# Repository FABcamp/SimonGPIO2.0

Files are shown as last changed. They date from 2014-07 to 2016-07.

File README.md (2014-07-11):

SimonGPIO2.0
============

SimonGPIO files for UCI fabcamp 2.0

includes:
 - Eagle BRD files, requires the [Sparkfun Eagle library][] and [Adafruit Eagle library][]
[Sparkfun Eagle library]: <https://github.com/sparkfun/SparkFun-Eagle-Libraries>
[Adafruit Eagle library]: <https://github.com/adafruit/Adafruit-Eagle-Library>
 - Fritzing PCB layout with custom part files for [Square buttons sold by Adafruit][]
[Square buttons sold by Adafruit]: <http://www.adafruit.com/products/1010>
 - solidworks and STL files for the Case and a test model of the finished PCB
 - scratch files and [instructions][] for running the project
[instructions]: https://github.com/FabCamp/SimonGPIO2.0/blob/master/Documentation/Scratch%20Instructions.md
 - [Bill of Materials][] for the project
[Bill of Materials]: https://github.com/FabCamp/SimonGPIO2.0/blob/master/Documentation/Bill%20Of%20Materials.md
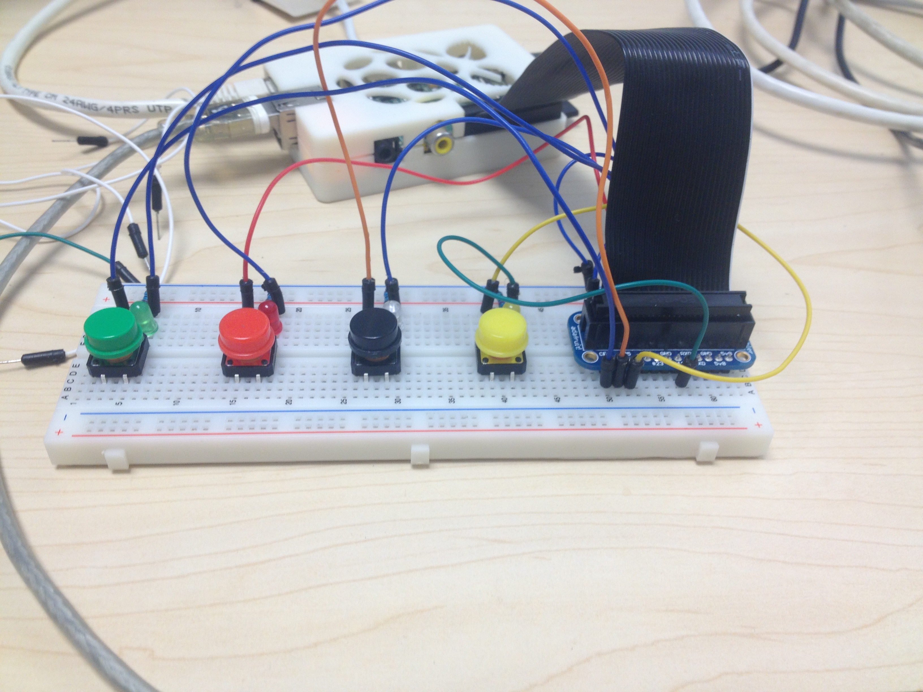
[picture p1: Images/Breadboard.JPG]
breadboard

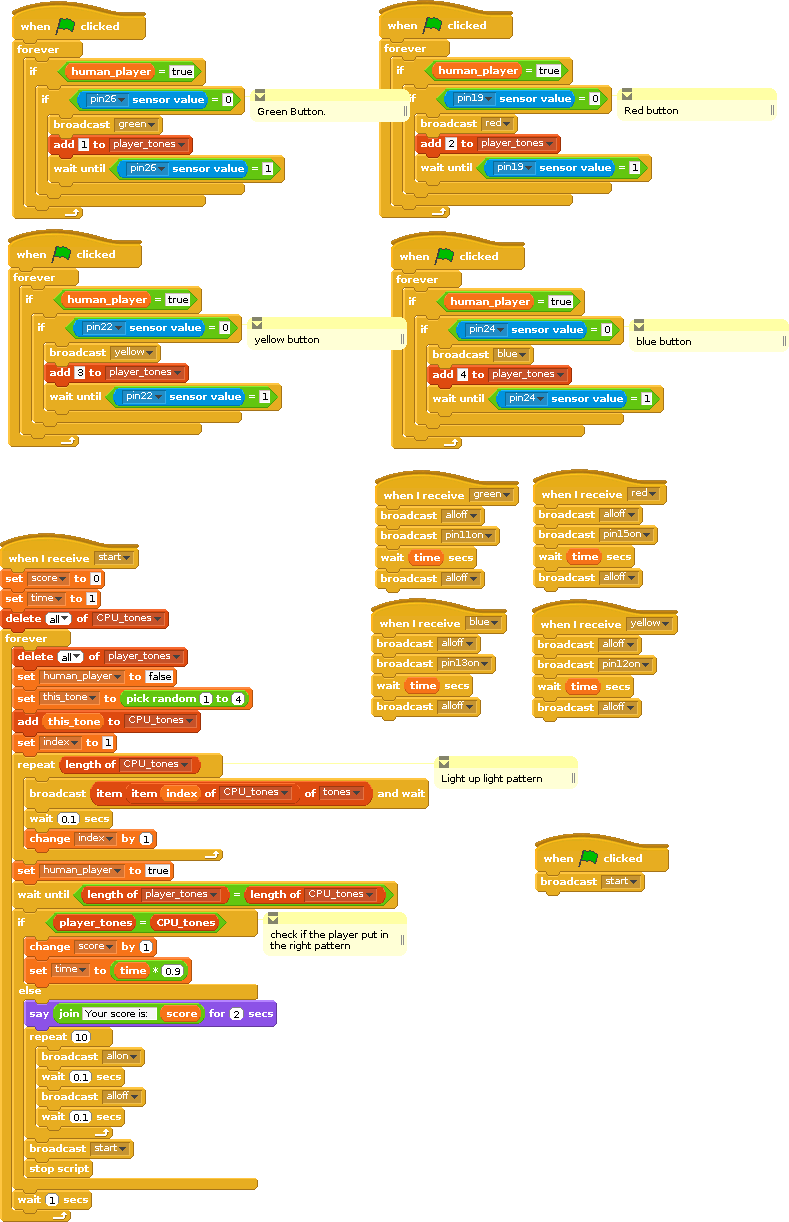
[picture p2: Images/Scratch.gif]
Scratch Code


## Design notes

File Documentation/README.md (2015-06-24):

Documentation
=============

######These documents will tell you everything you need to know about building the SimonGPIO project

- [Bill Of Materials][1]

[1]: https://github.com/FABcamp/SimonGPIO2.0/blob/master/Documentation/Bill%20Of%20Materials.md

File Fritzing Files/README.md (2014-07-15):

Fritzing Files
==============
Contents of this Directory:

1. [Fritzing Custom Parts.fzbz](https://github.com/FabCamp/SimonGPIO2.0/blob/master/Fritzing%20Files/Fritzing%20Custom%20Parts.fzbz): Custom parts for this project. All `.fzz` files here will work without this file, but they may be useful for future projects involving [square colorful buttons sold by Adafruit](http://www.adafruit.com/products/1010).
2. [Fritzing Diagram Full](https://github.com/FabCamp/SimonGPIO2.0/blob/master/Fritzing%20Files/Fritzing%20Diagram%20Full.fzz): The full diagram for the breadboard used in this project. Includes all parts necessary, which are the colorful square buttons (above) and [Adafruit Pi Cobbler]().

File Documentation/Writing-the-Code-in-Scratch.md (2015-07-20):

Writing The Code
================
######This page will guide you through writing the code for your simon game in the Scratch programming environment

_Teachers: Before giving these instructions, make sure you have [covered all the skills necessary!](https://github.com/FABcamp/SimonGPIO2.0/blob/master/Documentation/Topics-to-Cover-Teaching-Scratch.md)_

finished code

Setting Up
----------

When you start up the raspberry pi, you will see a desktop. The raspberry pi uses an operating system called Linux, which is similar to your Windows or Mac computers at home. To open ScratchGPIO, doubleclick on its icon on the desktop. If you open the normal Scratch, you will not be able to interface with your circuit. 

Once you have opened ScratchGPIO, go to file>new to clear the canvas and start a new project.

Beginning the Script
--------------------

First, we must have our script start when we begin the program. From the “control” tab on the upper left, drag into the canvas the first block, which should say “when (flag) clicked”. this will mean the block of code are creating will run as soon as we hit either the little green flag on the upper right, or hit the “enter” key on the keyboard. 

Now we need to set up our variables. in the variables tab, click `add variable` to create a variable called `score`, and another called `time`. In the lower half of this tab, click `add list` and create 2 lists called `CPU_tones` and  `player_tones` in the same way. Bring in 2 `set variable` blocks. change one to the `score` variable, and the other to the `time` variable. Set `score` to `0` and `time` to `1`. We must also reset our list of computer-created tones, so bring down the `delete () of []` block, setting it to **delete all of `CPU_tones`**. Now add a “forever” loop from the control tab. This will run *indefinitely* until we stop our script. Add another `delete` block to **delete all of `Player_tones`** inside the forever loop.

In our project, we also have a variable called `human_player`. This keeps track of when the player is in control of the simon game. first, the game must tell the player what the pattern is, so it is not the human player’s turn right now. add a block to **set `human_player` to `false`**. We should also have the game add numbers to this pattern, which will be between 1 and 4. each number will refer to one button or light on the board. under the variables tab, add a block to **add a value to `CPU_tones`**. In the value slot, drag in the block from the Operators tab to **create a random value** and change the second value to 4, not 10. 

Now the cumputer must play back the list of tones it has generated. This will step through each item in our list of `CPU_tones` and play each one out. Scratch doesnt have a function to do this for us, so we need to write it ourselves. Create a new variable called `index` to keep track of which item in our `CPU_tones` list we are playing. Add a block to **set `index` to 1** and add a block from the control tab to **repeat (value)**. For this value, add a block from variables for `Length of [CPU_tones]` Inside this, we will play the tone. Add a block to **broadcast a value**. for this value, bring in a block for `Item (x) of [CPU_tones]` and add the variable `index` for the item number. Now add a block to **wait 0.1 seconds**, and another to **change `index` by 1. How does this work? What we are saying, is first to run this chunk of code the same number of times as there are lights to turn on. on each of these, we are saying to play item x of the list, so if x is 1, we are broadcasting the first item, if x is 2, we are broadcasting the second item. Then we change x by 1 so the next value is used the next time the chunk of code runs. 

Now the human player must play back the pattern on the buttons. add another block to **set `human_player` to `true`**. For the human to be able to play the pattern, we must have the code detect when buttons are pressed, so we must work on another code block to do that. 

Reading the Button Inputs
-------------------------

Drag in another "When (flag) clicked" block from the control tab. under it, **add a forever loop**, and inside it, **add an if block from the control tab**. This will check if a condition is met. add another if block inside it. These blocks have to check:
  1. *if* it is the players turn to push the buttons 
  2. *if* the button is being pushed. 

From the Operators tab, **drag an "equals" block into each of the hexagonal sockets on the 2 if blocks.** in the first one, drag `human_player` into the first half of the `=` and type “true” into the second half. In the second if, drag a "sensor value" block from the sensing tab, and select `pin26`, the pin for our green button, from its drop down menu. Type “0” into the second half. In our circuit, the buttons are connected to ground, or 0, when they are pressed

Inside these 2 Ifs, add a yellow "broadcast block "from the control tab. in its drop down menu, select `new` and type in “1”. this will tell the red light to turn on later in the script. from the variables tab **add a block to add “1” to `player_tones.`** Under it, from the control tab, add a new block to "wait until <>". right click on the green equals on your bottom if, select duplicate, then drag it into the hexagonal socket on your Wait Until block. change the second value to “1”. this waits for the button to be released before allowing it to trigger again.

Duplicate this block 3 times, and change the pin values, broadcast values, and values to add to player_tones to match the 4 buttons on your board using the following table:

Deciding Wins and Losses
------------------------

|color |number|pin name|
|:-----|:----:|:---|
|green |1 |pin26 |
|red |2 |pin19 |
|blue  |3 |pin24 |
|yellow|4 |pin22 |

to let you press the buttons, go back to your first, main block of code and add a block from the control tab to "wait until < >". in it, add an "equals" block, and in each half, add the “length of” block from the variables tab. change them so one is `player_tones` and the other is `CPU_tones`. Order does not matter here. This waits until the player has pressed all the buttons they need to before advanceing in the game

if you start the script now, you should see you should be able to push the buttons, and the `player_tones` list will change as you press them. However, the game doesn't care what buttons you press, so we need to check if the buttons the player pressed (`player_tones`) is the same as the tones the computer created(`CPU_tones`). For this, we need a special kind of *if* called an *if else*. these are also under control. add one, and add another equals block into its hexagon socket. In an if else, the condition given is checked, and then runs the first half of the "E". however, if it is false, it will run the second half of the "E".

In each half of the hexagon socket, add `player_tones` and `CPU_tones`. Order doesn’t matter here. this checks if the list of buttons the player pressed is the same as, or equal to, the list of colors the computer presented them. *If* it is, the player won that round, and our code will lead into the first part of the “E”. *else*, the player lost, it will go to the second half of the “E”, and the game should end. 

If the player won, they should get another point, so add a block from variables to change score by one. We also want the game to go faster, so our time delay `time` should be changed. We can change this to 9/10 of what it was in the last round by adding a few blocks to **set time to (time * 0.9).** The multiplication block is under operators. Feel free to change 0.9 to another number, but if you make it too low (like 0.1), the game will get too fast too quickly. 

Under else, we need to end the game. from the Looks tab, add a block to say “you made a mistake” for 2 seconds. also add a "stop all" block from control. Finally, add a block to wait `1` second from the control tab, to make sure the game doesn't start playing the next pattern until the player is ready. 

Adding Outputs for LEDs
-----------------------

If you play the game now, it may be difficult, because the lights aren't turning on!

we need to add some blocks to turn the lights on! If you look back over our script, we have blocks broadcasting lots of numbers. This is like they are yelling into the air “ONE!” as loud as possible, and another block can listen until they hear that symbol. 

Under control, add a block for "When i receive []". Under this, we will add some more broadcasts to turn the lights on. Another thing our broadcasts can do is control electricity! to do this, we will make more broadcasts, saying things like `allon` or `pin15on` or `pin12off`. these talk to the raspberry pi telling it to change its outputs. Under this, add 2 broadcast blocks, a wait block, and another broadcast block. Duplicate this 3 times and change the broadcasts in the top blocks to numbers 1-4. in the first broadcast, have it say “alloff”, the second say “pin#on” and have the third be “pin#off”. this number should match the broadcast number (which color it is) from this table. You should be done now, enjoy the game!

|number|on message|off message|
|:----:|:---:|:---:|
|1 |pin11on |pin11off |
|2 |pin15on |pin15off |
|3 |pin13on |pin13off |
|4 |pin12on |pin12off |

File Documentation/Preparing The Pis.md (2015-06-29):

Preparing The Raspberry Pis
=================

###### Initial setup

We bought a Cana kit Raspberry Pi Complete Starter Kit for each student. The kit includes the Pi, a case, an SD card, a Wifi adapter, a power supply, and an HDMI cable. Unfortunately, we do not have acess to the university Wifi without registering the MAC addresses of each pi, so all software had to be installed beforehand. In the process of opening each kit to install the cases, we removed the SD card for cloning.

-----------------

###### Cloning the SD cards

We used a [Startech.com USB cloner][1] to clone all the SD cards (though a USB hub and some simple scripting could also work) along with some cheap $1.50 micro SD card reades from Dyso Japan. 

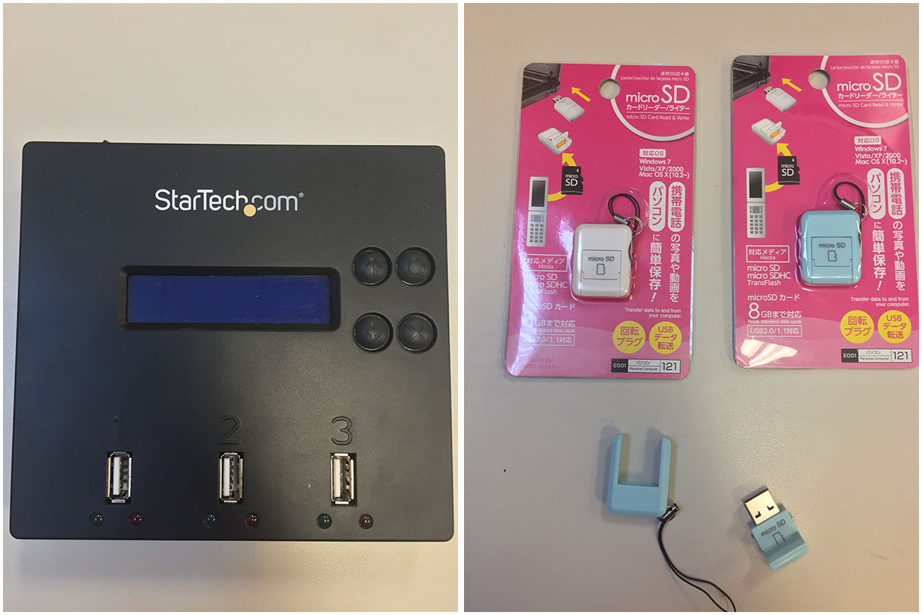
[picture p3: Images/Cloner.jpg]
Cloner


[1]: http://www.startech.com/HDD/Duplicators/USB-1-to-2-Standalone-Flash-Drive-Duplicator-Eraser~USBDUP12
[2]: https://raw.githubusercontent.com/FABcamp/SimonGPIO2.0/master/Images/Cloner.jpg

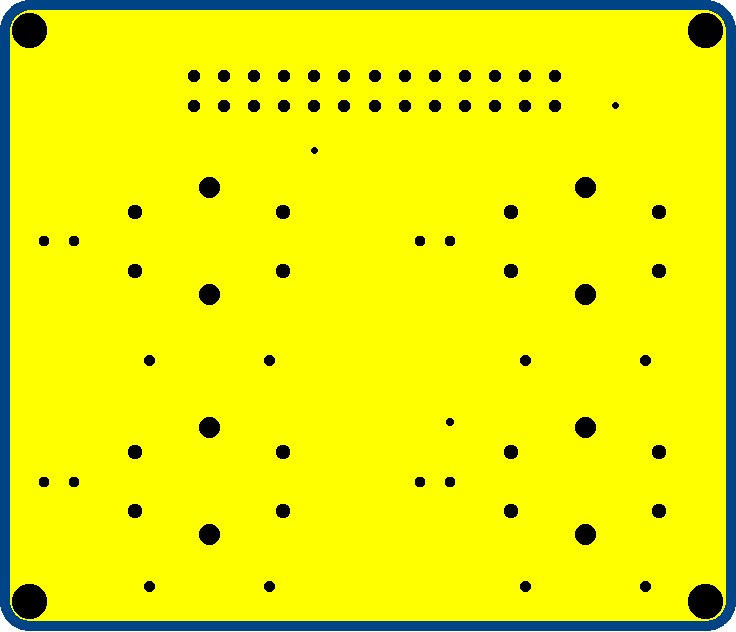
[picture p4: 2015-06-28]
Images/PCB_bottom.png

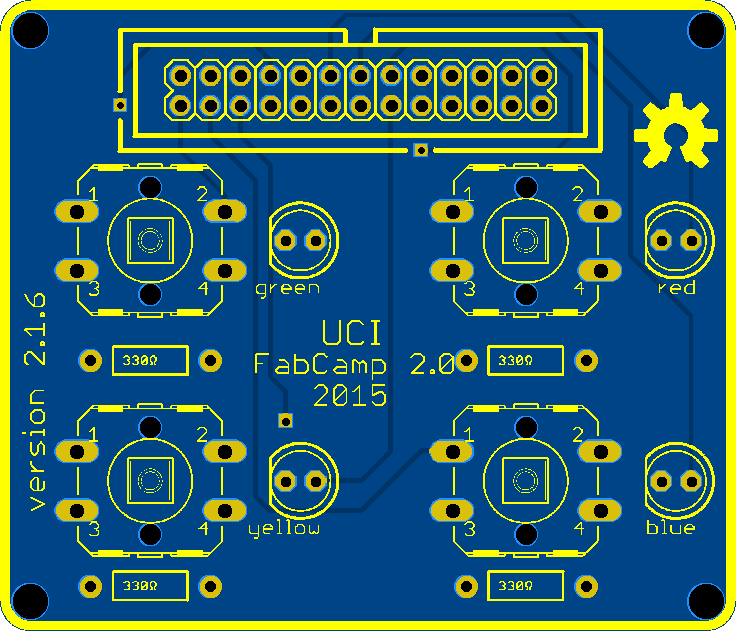
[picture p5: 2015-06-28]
Images/PCB_top.png

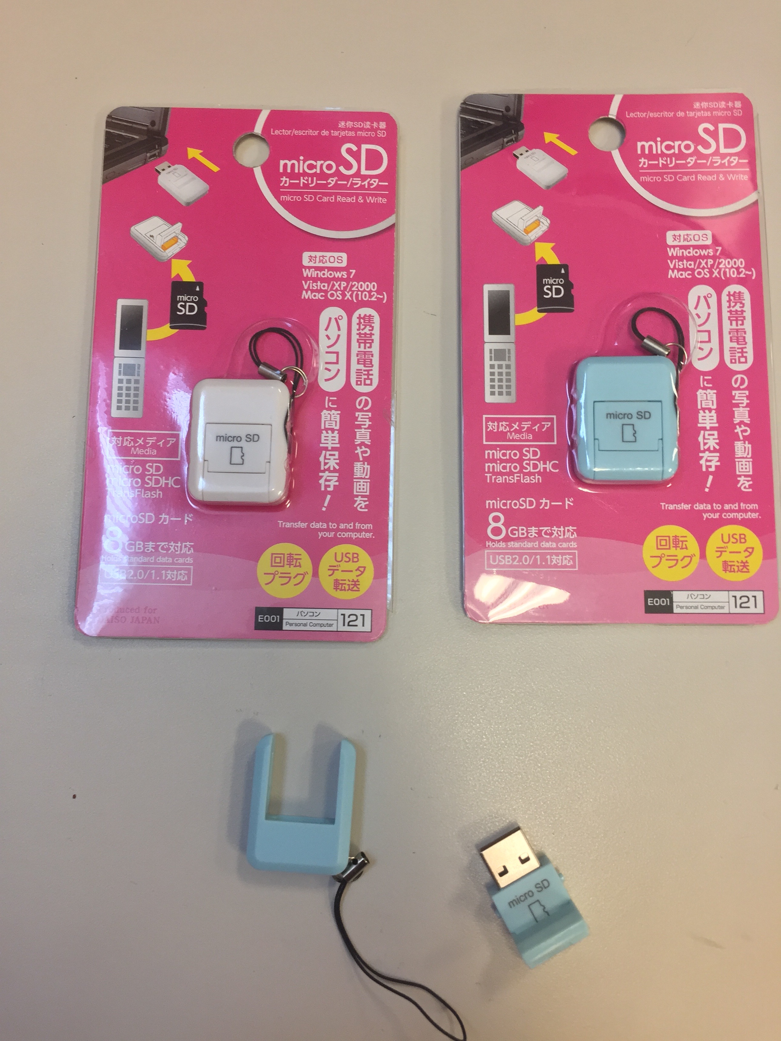
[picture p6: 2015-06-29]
Images/Readers.jpg

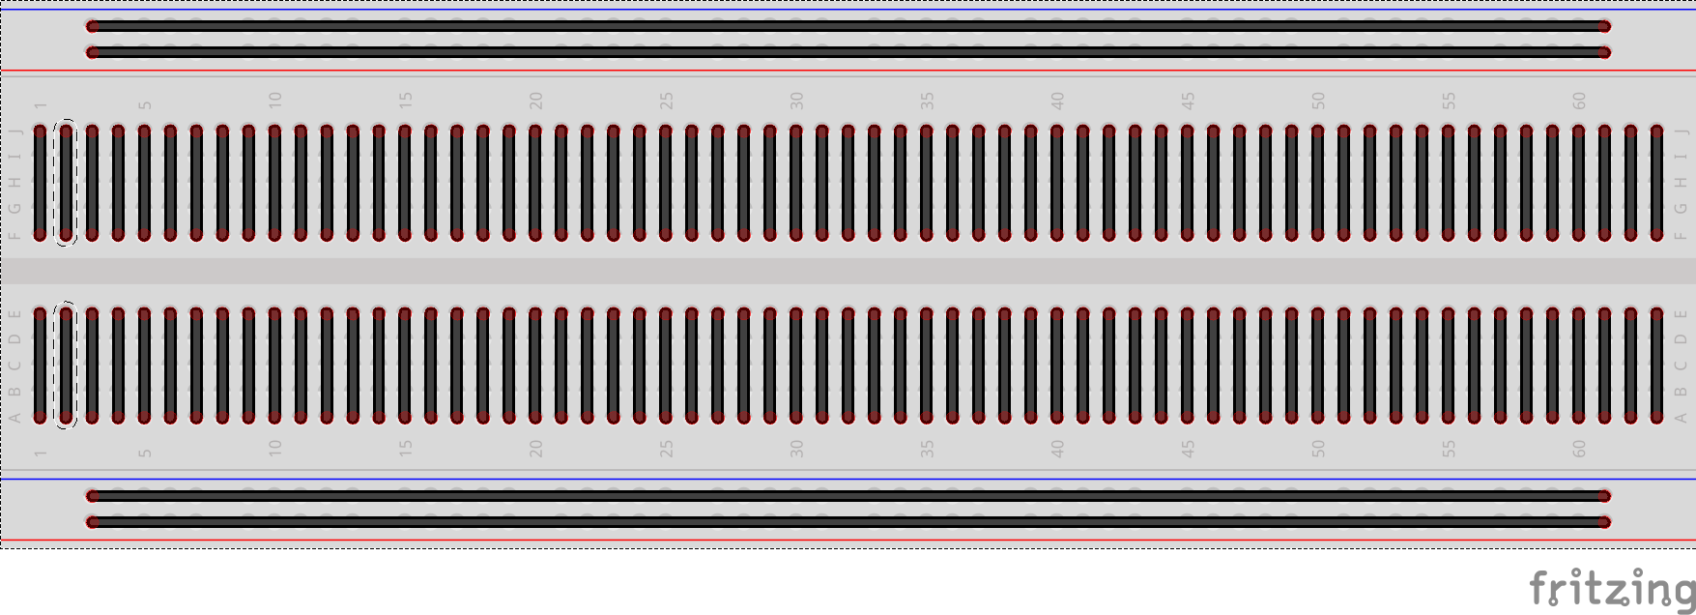
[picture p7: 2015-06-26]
Images/Breadboard Connections.png

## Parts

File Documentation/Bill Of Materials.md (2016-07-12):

Bill Of Materials
=================

###### All the materials necessary to build the SimonGPIO2.0 Project

--------------------------------------------------------------------

#### For Each Student

| Item | Source | Product SKU  | Unit Price | Quantity  | Subtotal |
| --- | --- |:---:| --- |:---:| --- |
| Raspberry Pi 3 | [Newark][1] | #77Y6520  | $35.00 | 1 | $35.00 |
| Raspberry pi Case | [Newark][17] | #77Y6512  | $6.99 | 1 | $6.99 |
| Micro SD card | [Amazon][14] |  B01BMJ25ZA  | $7.49 | 1 | $7.49 |
| Power Supply | [Amazon][15] |  B00MARDJZ4  | $10.00 | 1 | $10.00 |
| HDMI Cable | [Monoprice][16]| #3871 | $2.00 | 1 | $2.00 |
| Downgrade Cable | [Adafruit][2]  | #1986 | $2.95 | 1 | $2.95 |
| HDMI-DVI adapter | [Monoprice][3] | #2029 | $2.28 | 1 | $2.28 |
| Breadboard with Jumpers| [Amazon][4] |  B008A9UP1C  | $11.69 | 1 | $11.69 |
| Pi-Cobbler W/ Cable | [Adafruit][5]  | #1754 | $6.25 | 1 | $6.25 |
| Colored Square buttons | [Adafruit][7]  | #1010 | $5.95 | 1/3 | $1.98 |
| Assorted LEDs (RGBY) | [Sparkfun][8]  | Com-12062  | $2.95 | 1/5 | $0.59 |
| 330Ω resistors x20 | [Digikey][9] | 330ETR-ND  | $0.01 | 1/5 | $0.01 |
| 26 pin shrouded header | [Digikey][11]  |  ED10526-ND  | $0.40 | 1 | $0.40 |
| Plastic Spacer | [McMaster][12] |  #92825A005  | $6.18 | 1/5 | $1.24 |
| 316 Steel Screw | [McMaster][13] |  #90184a110  | $7.02 | 1/20 | $0.35 |
| Total: | | | | | **$89.21** |

[1]: http://www.newark.com/raspberry-pi/raspberrypi3-modb-1gb/sbc-raspberry-pi-3-mod-b-1gb-ram/dp/77Y6520
[2]: https://www.adafruit.com/products/1986
[3]: http://www.monoprice.com/Product?c_id=104
[4]: http://www.amazon.com/microtivity-830-point-Experiment-Breadboard-Jumper/dp/B008A9UP1C
[5]: http://www.adafruit.com/products/1754
[6]: http://www.adafruit.com/products/1986
[7]: http://www.adafruit.com/products/1010
[8]: https://www.sparkfun.com/products/12062
[9]: http://www.digikey.com/product-detail/en/yageo/CFR-12JR-52-330R/330ETR-ND/4162
[10]: http://bayareacircuits.com
[11]: http://www.digikey.com/product-detail/en/on-shore-technology-inc/302-S261/ED10526-ND/2794237
[12]: http://www.mcmaster.com/#92825a005/=xu4ogi
[13]: http://www.mcmaster.com/#90184a110/=xu4nd7
[14]: http://www.amazon.com/Kingston-microSDHC-Memory-SDC4-8GBET/dp/B00200K1TS/
[15]: http://www.amazon.com/CanaKit-Raspberry-Supply-Adapter-Charger/dp/B00MARDJZ4/
[16]: http://www.monoprice.com/product?p_id=3951
[17]: http://www.newark.com/multicomp/cbpiblox-wht/raspberry-pi-enclosure-abs-white/dp/77Y6512

 For the Soldering section, some parts can be reused from Breadboard section of the project. PCB costs will depend on your fabhouse. We got 65 for $500 from [Bay Area Circuits][10]. You will also need solder, soldering irons, copper wick, etc. Make sure to buy extra components in case some get destroyed during assembly!

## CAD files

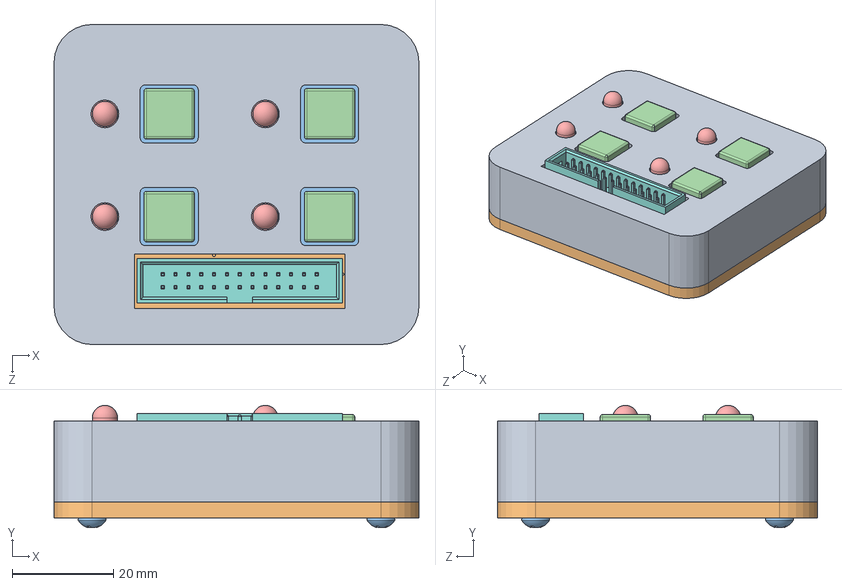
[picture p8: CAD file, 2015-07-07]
Project Case Files/Solidworks Files/Assembled.SLDASM
72.2 x 24.2 x 63.3 mm
case
PCB
button x 4
Cap x 4
LED Head x 4
LED Leads x 4
Resistor .4 x 4
header
spacer x 4
Bottom
Screw x 4

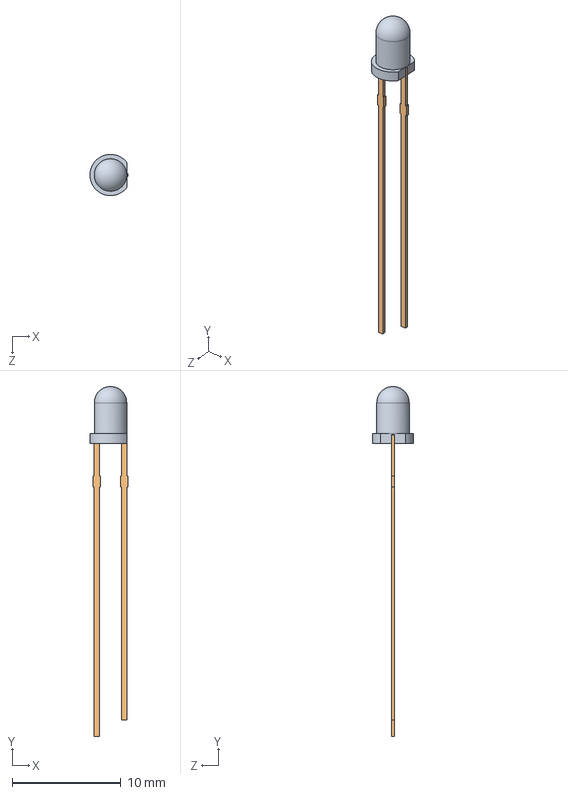
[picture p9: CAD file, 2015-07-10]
Project Case Files/Solidworks Files/Components/PCB/LED short.SLDASM
3.52 x 32.2 x 3.79 mm
LED Head
LED Leads

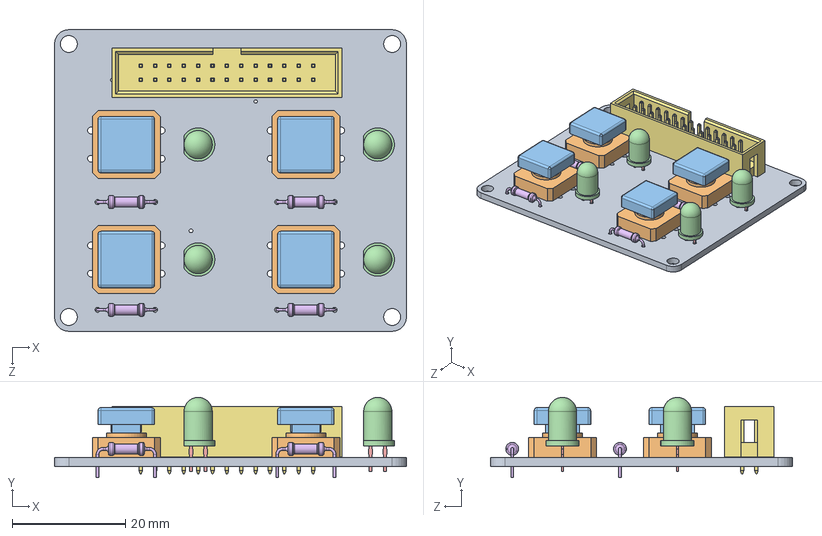
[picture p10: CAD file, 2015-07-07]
Project Case Files/Solidworks Files/Components/Assembled PCB.SLDASM
62.2 x 14.2 x 53.3 mm
PCB
button x 4
Cap x 4
LED Head x 4
LED Leads x 4
Resistor .4 x 4
header

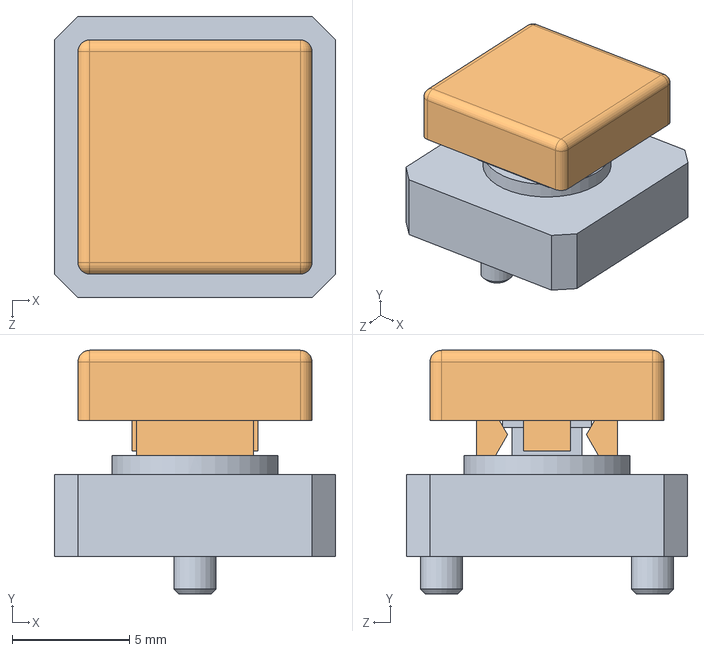
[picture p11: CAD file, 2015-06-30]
Project Case Files/Solidworks Files/Components/PCB/Button Assembly.SLDASM
12.0 x 10.4 x 12.0 mm
button
Cap

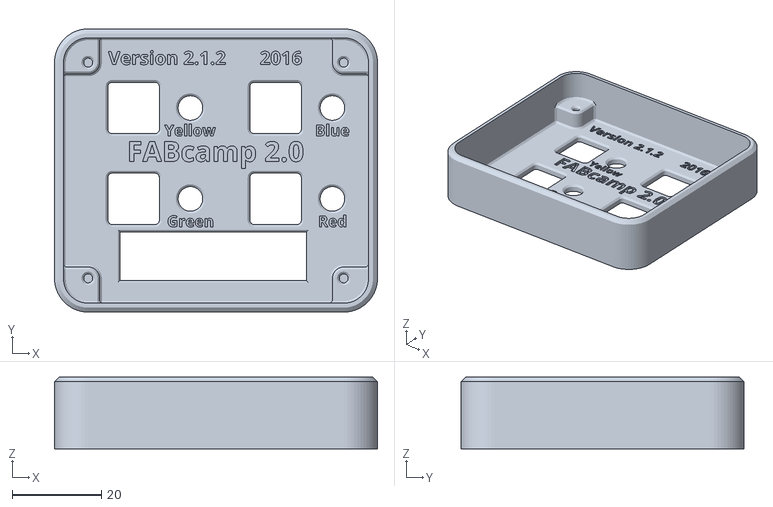
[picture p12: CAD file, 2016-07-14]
Project Case Files/case.STL
72.2 x 63.3 x 16.0

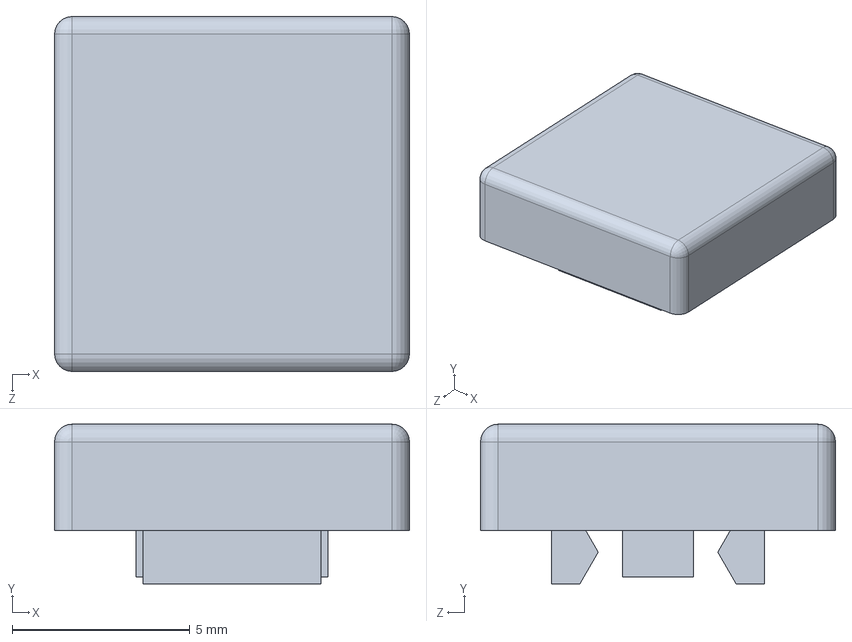
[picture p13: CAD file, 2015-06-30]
Project Case Files/Solidworks Files/Components/PCB/Button/Cap.SLDPRT
10.0 x 4.50 x 10.0 mm

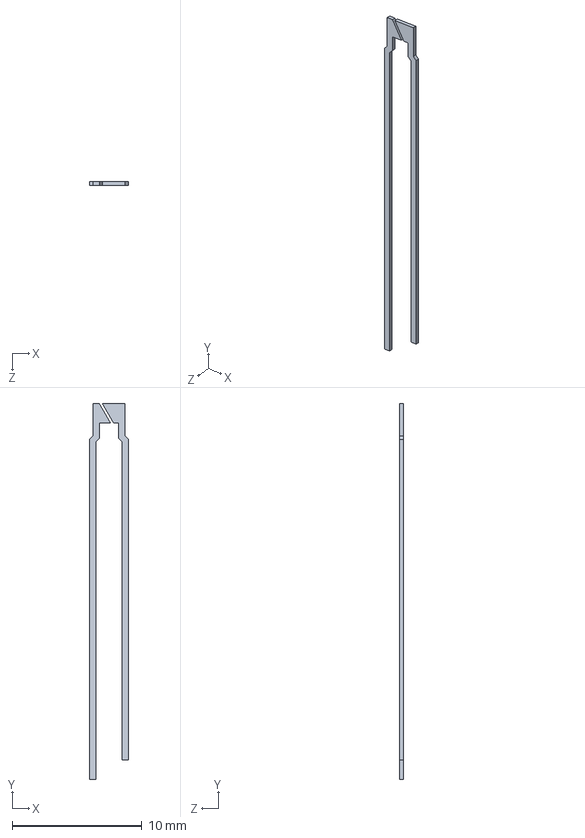
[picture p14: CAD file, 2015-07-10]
Project Case Files/Solidworks Files/Components/PCB/LED/LED Leads.SLDPRT
3.04 x 29.0 x 0.3 mm

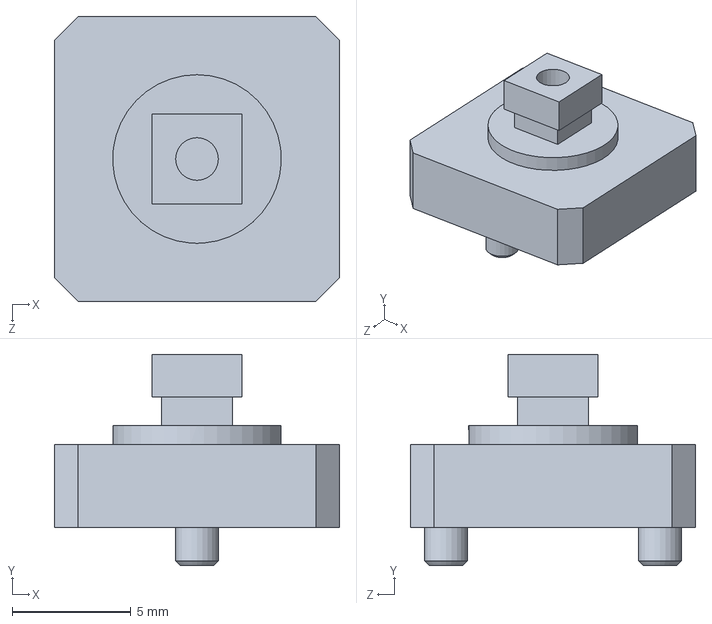
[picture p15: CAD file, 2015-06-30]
Project Case Files/Solidworks Files/Components/PCB/Button/button.SLDPRT
12.0 x 8.90 x 12.0 mm

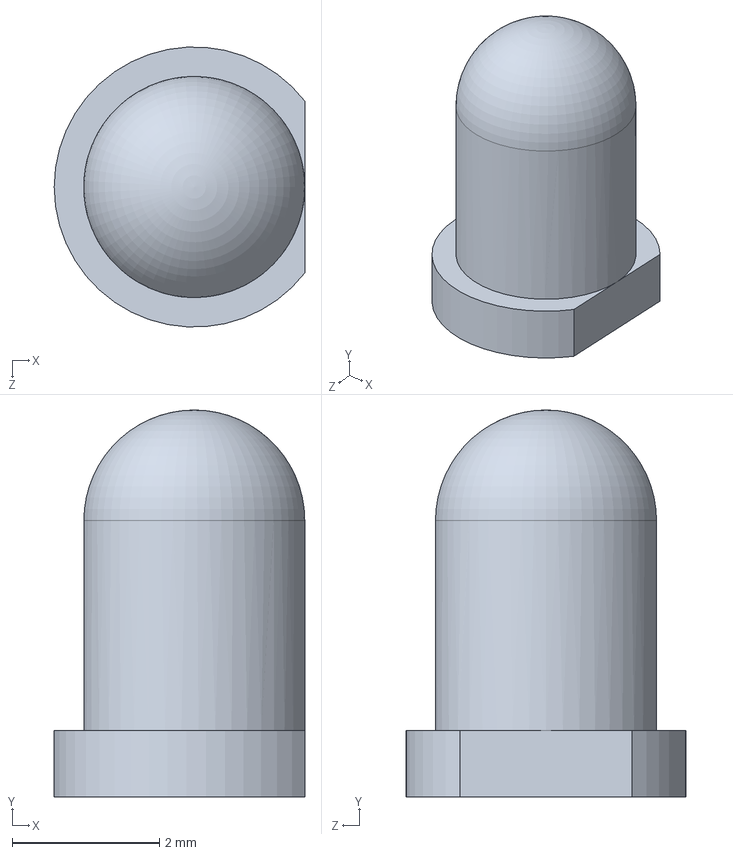
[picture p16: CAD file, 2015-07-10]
Project Case Files/Solidworks Files/Components/PCB/LED/LED Head.SLDPRT
3.40 x 5.25 x 3.79 mm

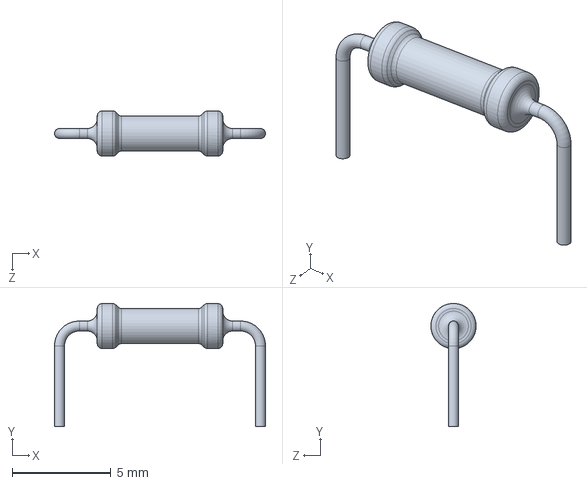
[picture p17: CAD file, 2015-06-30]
Project Case Files/Solidworks Files/Components/PCB/Resistor .4.SLDPRT
10.7 x 6.22 x 2.29 mm

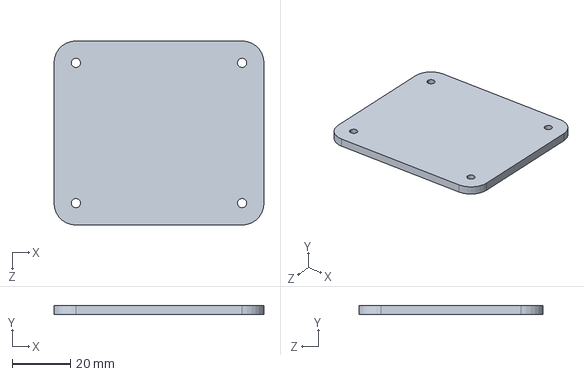
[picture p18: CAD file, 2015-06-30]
Project Case Files/Solidworks Files/Components/Bottom.SLDPRT
72.2 x 3.17 x 63.3 mm

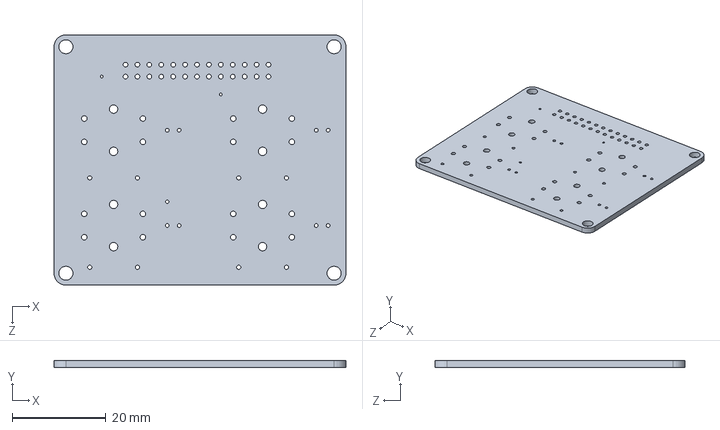
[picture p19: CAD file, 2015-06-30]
Project Case Files/Solidworks Files/Components/PCB/PCB.SLDPRT
62.2 x 1.57 x 53.3 mm

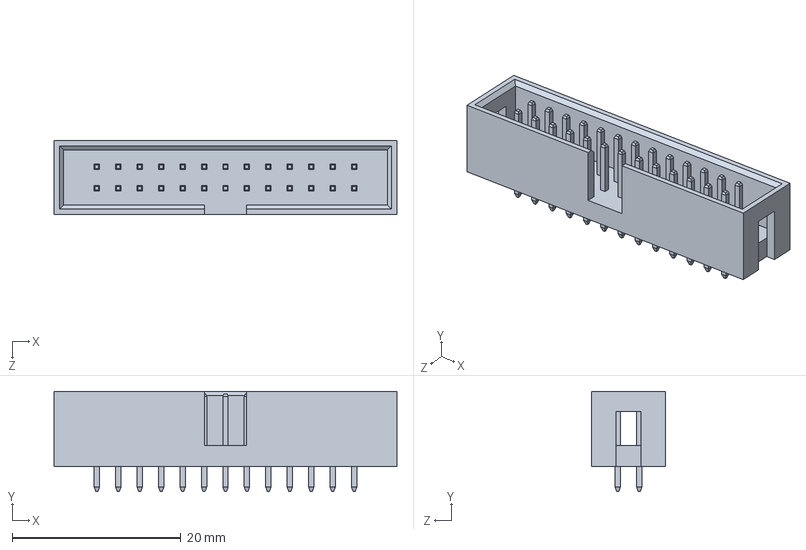
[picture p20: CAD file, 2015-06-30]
Project Case Files/Solidworks Files/Components/PCB/header.SLDPRT
40.6 x 11.9 x 8.80 mm

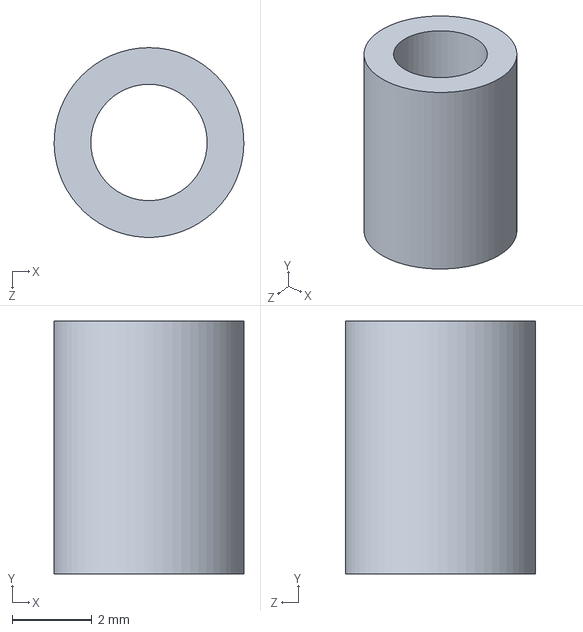
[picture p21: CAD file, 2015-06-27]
Project Case Files/Solidworks Files/Components/spacer.SLDPRT
4.76 x 6.35 x 4.76 mm

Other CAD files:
Project Case Files/Solidworks Files/Components/case.SLDPRT
Project Case Files/Bottom.DWG
Project Case Files/Solidworks Files/Components/Screw.SLDPRT
Project Case Files/Solidworks Files/Drawings/Bottom.SLDDRW
Project Case Files/Solidworks Files/Drawings/Case Assembled.SLDDRW
Project Case Files/Solidworks Files/Drawings/case.SLDDRW

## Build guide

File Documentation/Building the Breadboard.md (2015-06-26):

######This page will guide you through the process of assembling the breadboard you will use to prototype SimonGPIO2.0. 

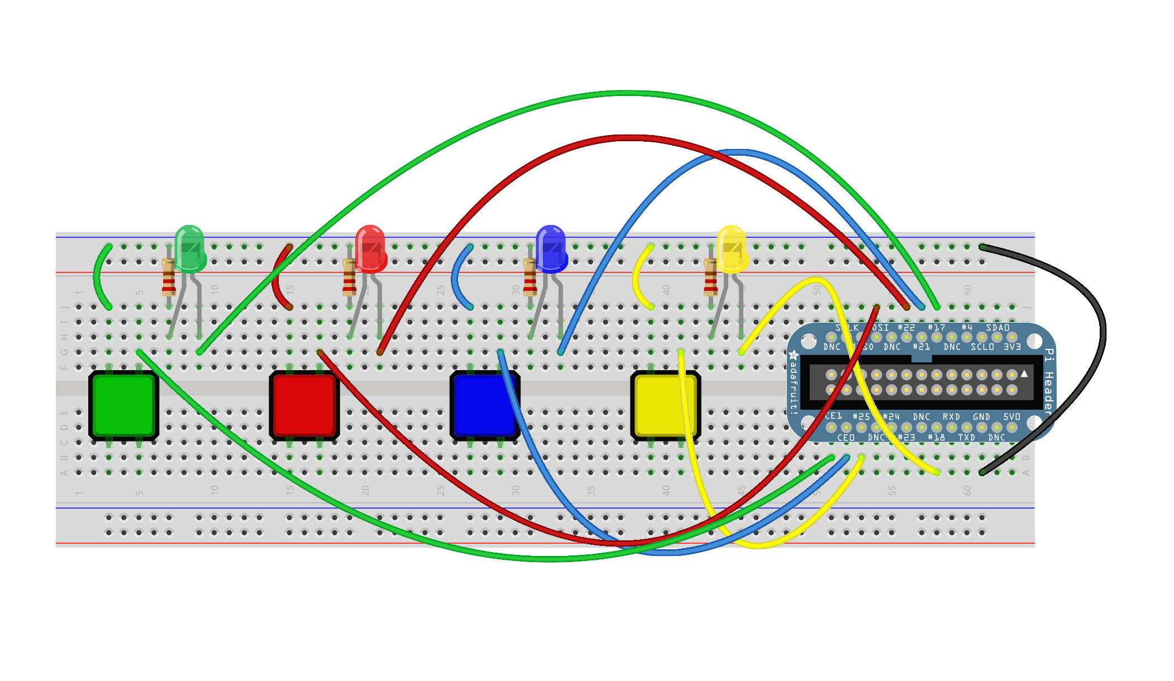
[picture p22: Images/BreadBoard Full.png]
Welcome To Your Doom!


Placing the Components
----------------------

Take your 4 buttons, Green, Red, Blue, and Yellow, and place them on the left 2/3 of the breadboard. One the right side, place your breakout board (the blue or black circuit board in your Raspberry Pi kit) with the notched side up. Don't worry if the text is upside-down. 

Now take your LEDs. Place them to the right of your buttons on the breadboard, with the shorter leg, or ground, on the left. This is very important, as LEDs will only work with the current going in one direction, and will block electricity from going in the other direction. Now these LEDs need to be connected to ground, but need a current limiting resistor to keep them from blowing. Take your four 330Ω resistors from your kit, and bend both sides to be at right angles. Use your wire cutters to cut the legs halfway down from the body of the resistor. Use these to connect the ground pins of your LEDs with the ground power rail above. Remember, anything in the same vertical column on one side of the breadboard will be connected, so do not attempt to place the leg of the resistor in the same hole as the LED! Your breadboard should now look like the one below.

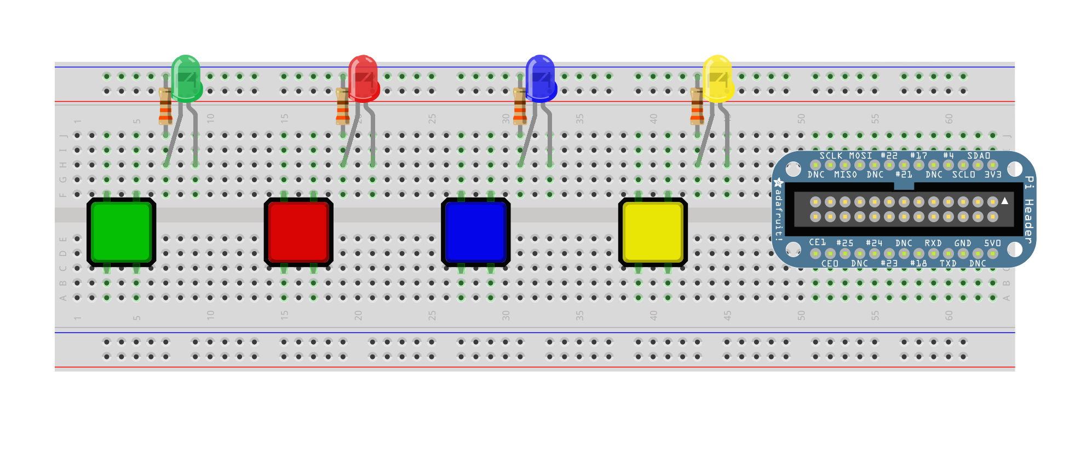
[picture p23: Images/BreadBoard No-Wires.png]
Breadboard conponents only


Connecting Components to Ground
-------------------------------

Take out one short jumper cable of each color: Red, Green, Blue, and Yellow. Use these to connect the upper left leg of each button with the Ground rail above. Now we have connected all the buttons to the ground rail, but we still need to connect the ground rail to the ground from our Raspberry Pis. Run a shor black jumper from any of the pins on the breakout board labeled "GND" to the upper ground rail. Your breadboard should look like the one below

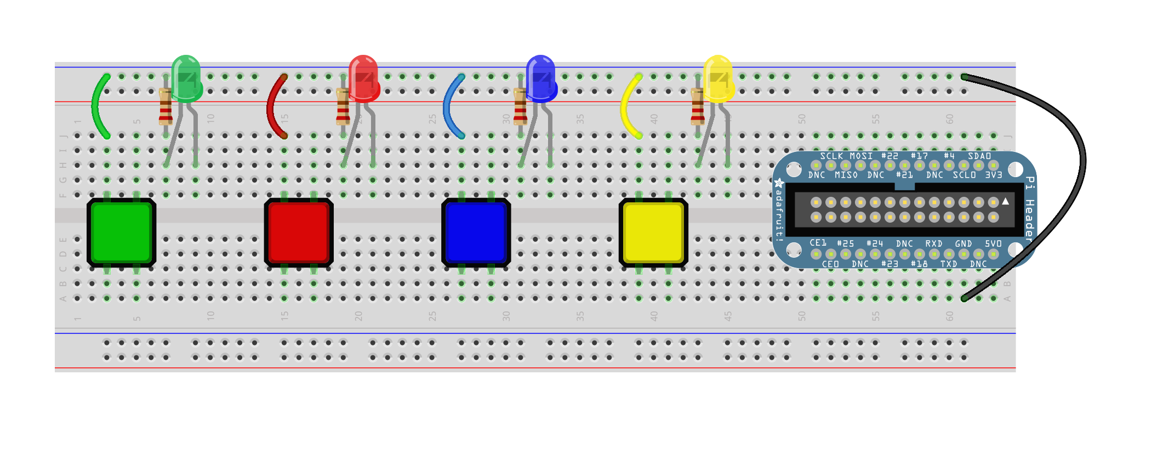
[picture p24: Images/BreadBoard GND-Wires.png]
Ground wires only


Connecting the LEDs
-------------------

Connect the right-hand legs (the posative leads) of the LEDs to the appropriate pins on the breakout board using the table below. The pins on the raspberry pi are named strangely, so make sure you dont get confused. Use the medium and long jumpers for this. You can color-code these like you did the ground wires to make troubleshooting easier.

|Color |Pin Number|Pin Name on Breakout|
|---|---|---|
|green |11 |p17 |
|red |15 |p22 |
|blue  |13 |p21 |
|yellow|12 |p18 |

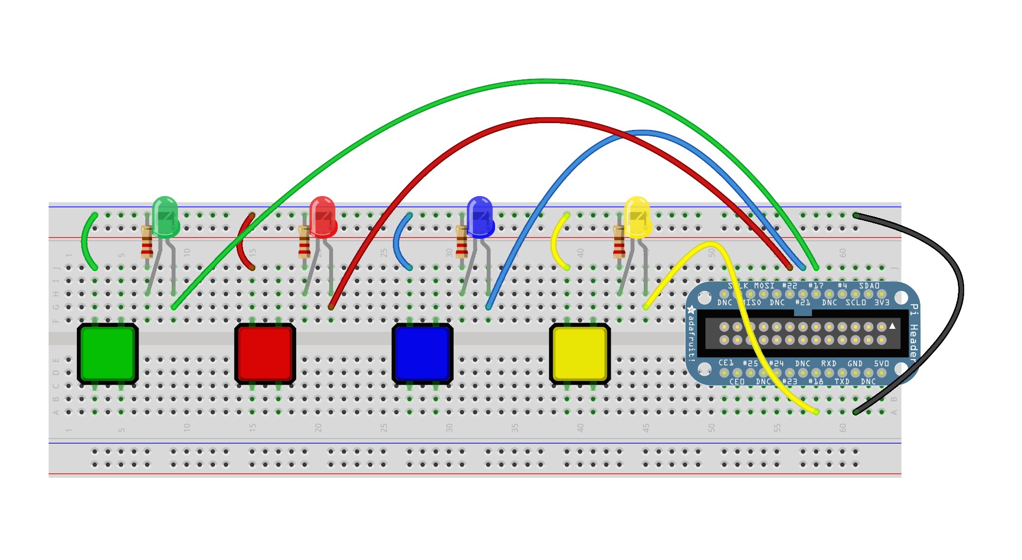
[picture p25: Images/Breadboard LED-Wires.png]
LED wires


Connecting the Buttons
----------------------

Now connect the upper right legs of the buttons on your board to the correct pins, again shown in the table below. You can also color-code these if you wish. Note that the buttons are connected to ground, so when you press the button, it will read a 0 (gnd), and 1 when it is released (there is some circuitry inside the Pi itself that makes the pins connected to +v, or 1, by default. This is known as a "pull up" because it pulls the signal "up" to a digital 1 by default)

|Color |Pin Number|Pin Name on Breakout|
|---|---|---|
|green |26 |CE1 |
|red |19 |MOSI |
|blue  |24 |CE0 |
|yellow|22 |p25 |

finished board

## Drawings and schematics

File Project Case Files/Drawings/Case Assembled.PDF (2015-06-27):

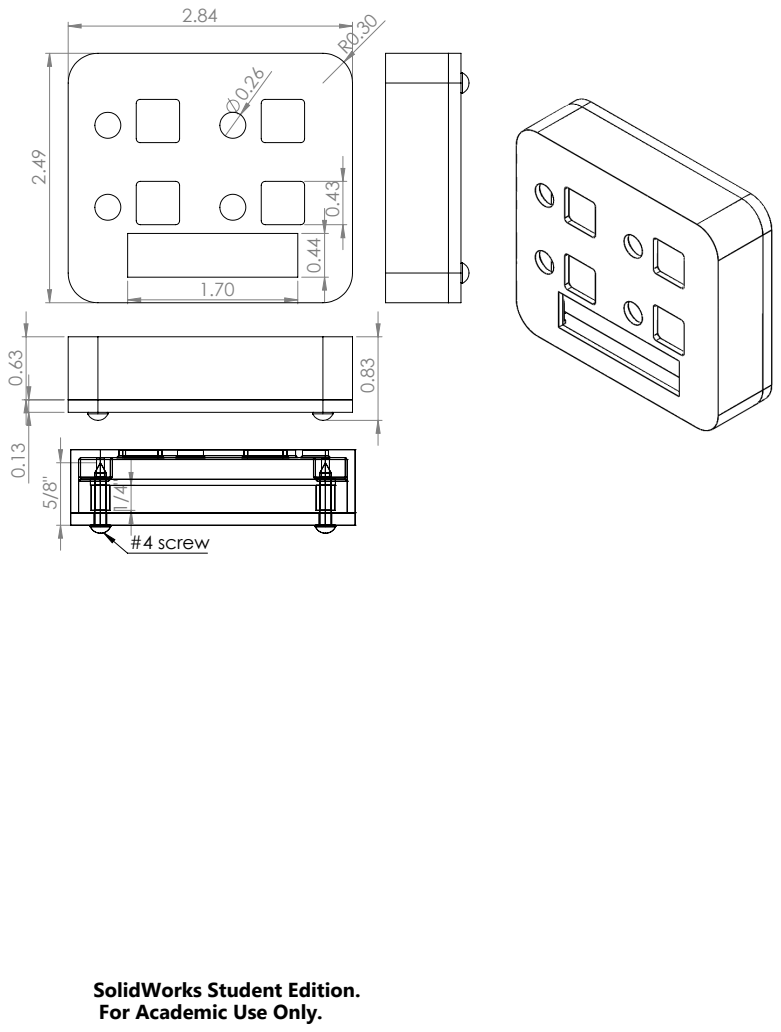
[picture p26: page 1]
#4 screw

SolidWorks Student Edition.
For Academic Use Only.

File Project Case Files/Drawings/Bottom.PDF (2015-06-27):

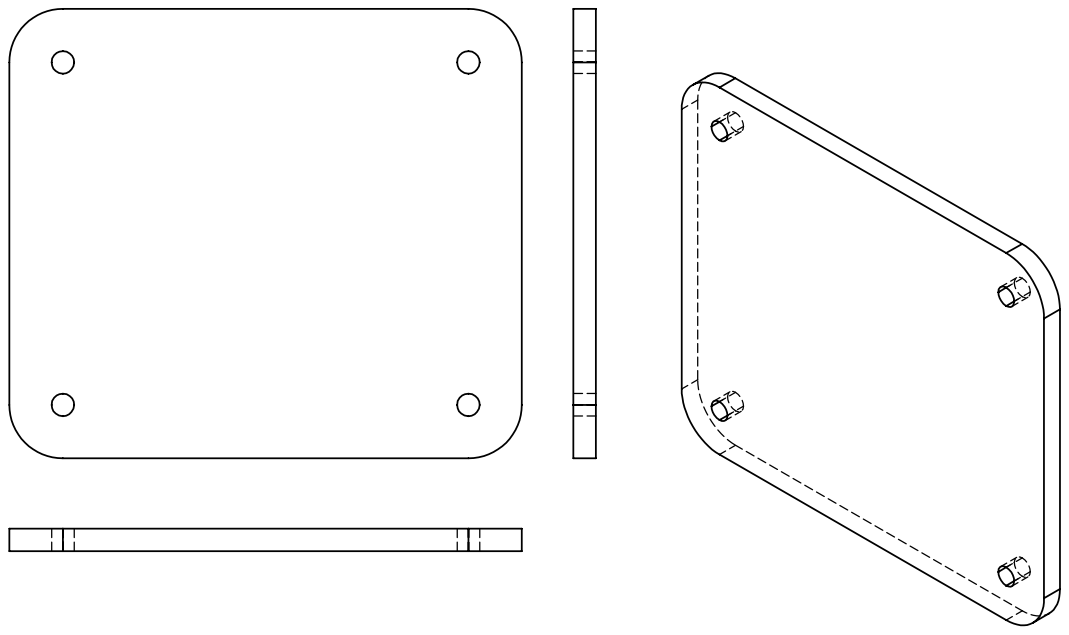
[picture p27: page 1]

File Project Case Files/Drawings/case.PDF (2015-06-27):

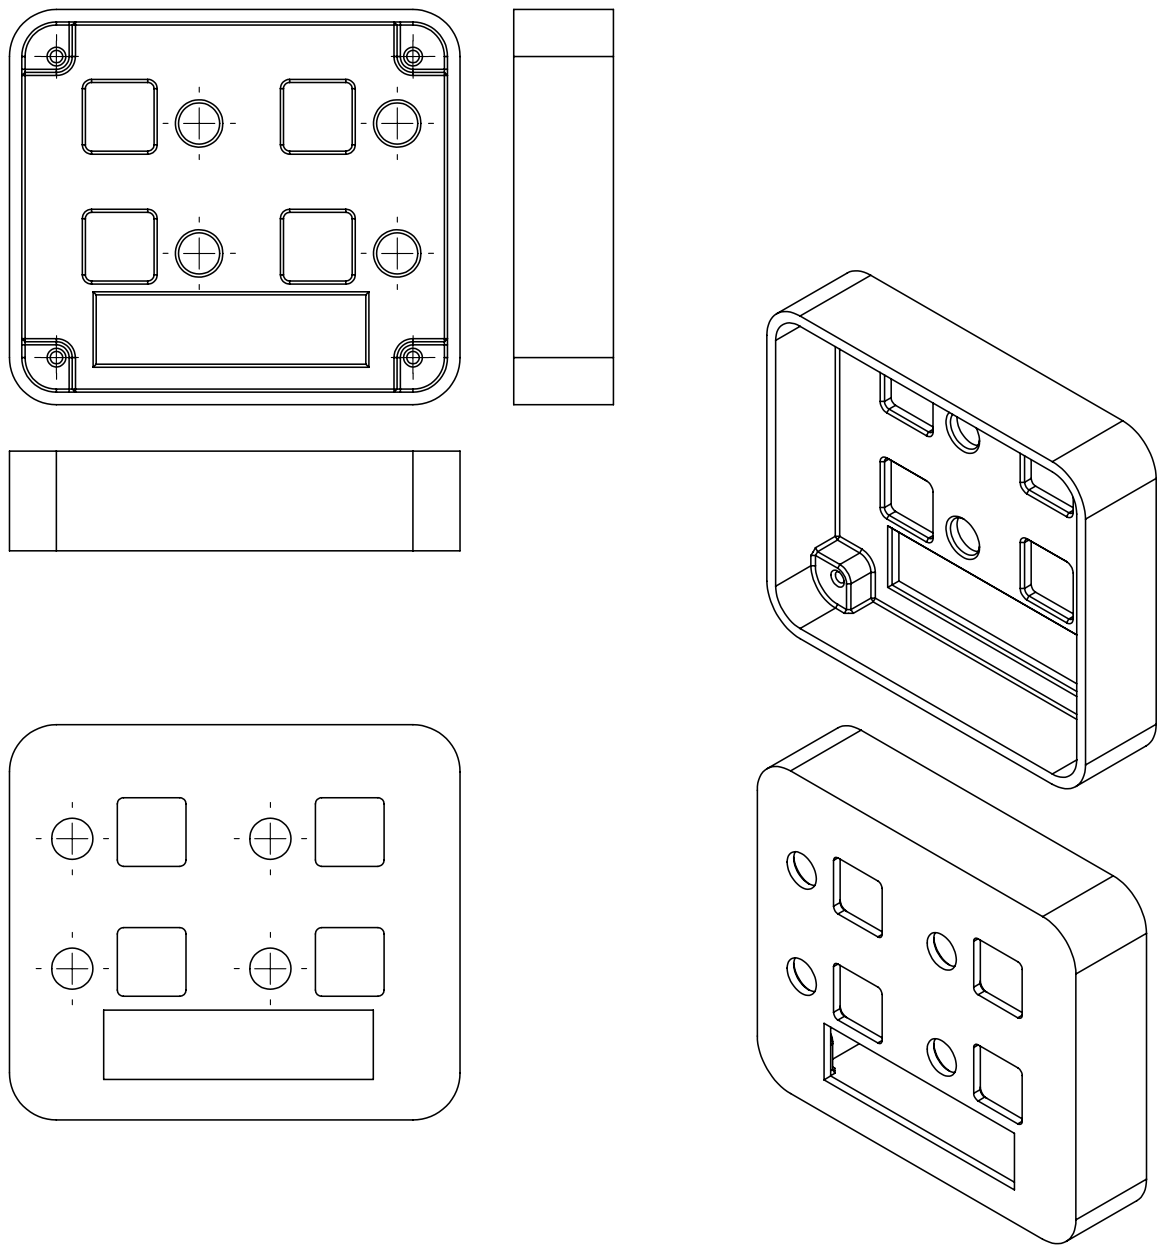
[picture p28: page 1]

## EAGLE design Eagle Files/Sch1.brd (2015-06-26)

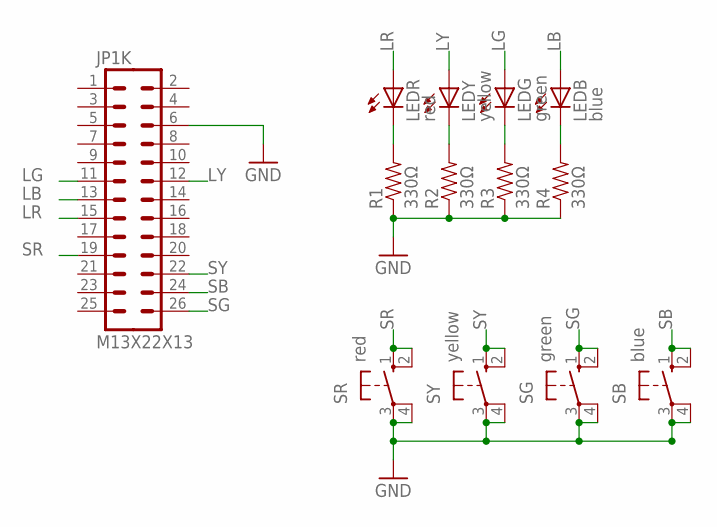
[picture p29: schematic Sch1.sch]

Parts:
JP1K: M13X22X13; 2X13
LEDB: blue; LED5MM
LEDG: green; LED5MM
LEDR: red; LED5MM
LEDY: yellow; LED5MM
R1, R2, R3, R4: 330Ω; AXIAL-0.4
SB: blue; B3F-40XX
SG: green; B3F-40XX
SR: red; B3F-40XX
SY: yellow; B3F-40XX

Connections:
GND: JP1K.6, R1.P$1 (1), R2.P$1 (1), R3.P$1 (1), R4.P$1 (1), SB.3, SB.4 (P1), SG.3, SG.4 (P1), SR.3, SR.4 (P1), SY.3, SY.4 (P1)
LB: JP1K.13, LEDB.A
LG: JP1K.11, LEDG.A
LR: JP1K.15, LEDR.A
LY: JP1K.12, LEDY.A
unnamed: LEDR.K (C), R1.P$2 (2)
unnamed: LEDY.K (C), R2.P$2 (2)
unnamed: LEDG.K (C), R3.P$2 (2)
unnamed: LEDB.K (C), R4.P$2 (2)
SB: JP1K.24, SB.1 (S), SB.2 (S1)
SG: JP1K.26, SG.1 (S), SG.2 (S1)
SR: JP1K.19, SR.1 (S), SR.2 (S1)
SY: JP1K.22, SY.1 (S), SY.2 (S1)

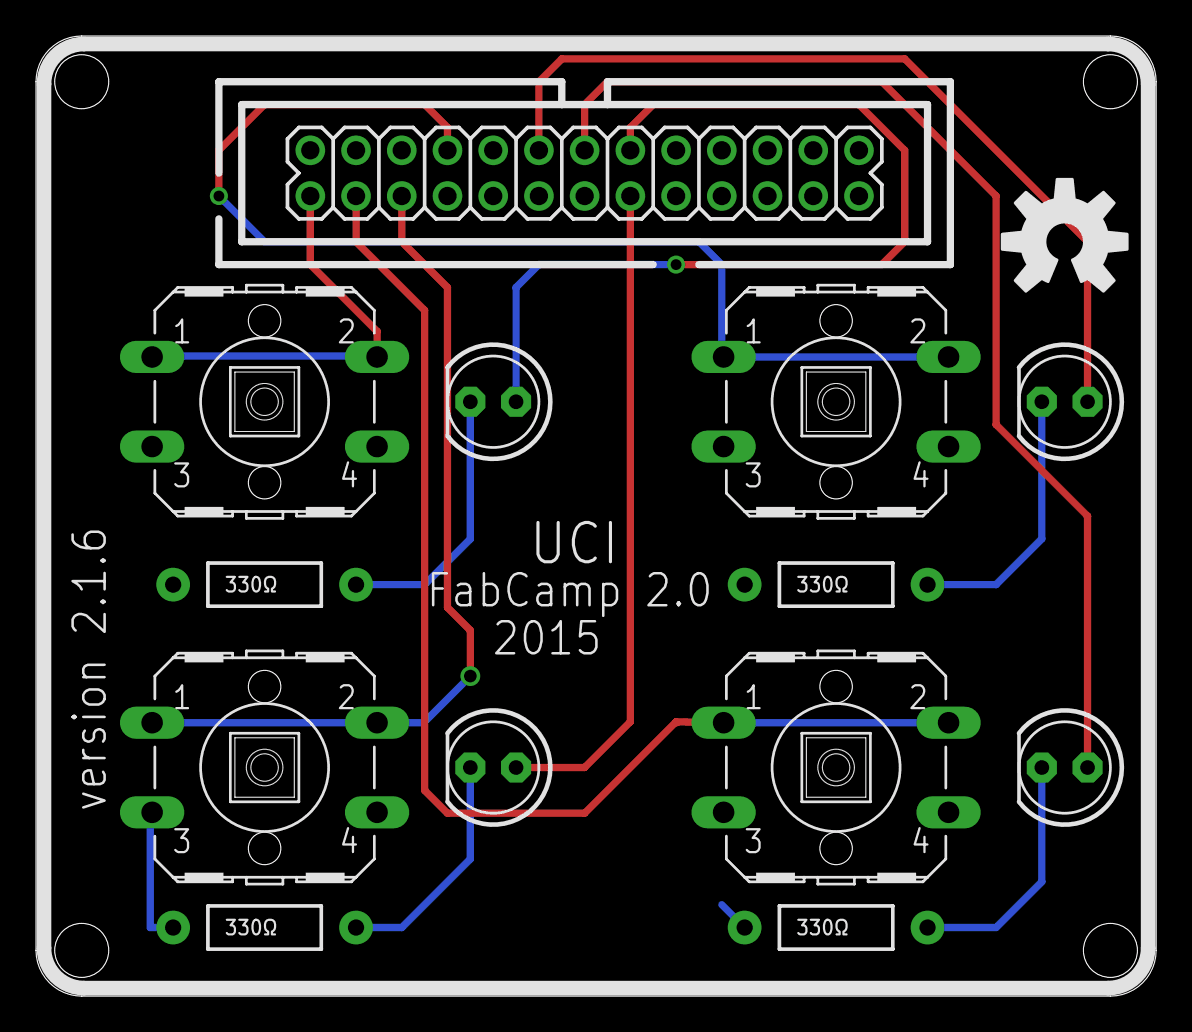
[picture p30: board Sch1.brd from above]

Board: 2 copper layers, 62.2 x 53.3 mm, 14 parts (0 on the bottom side), 13 nets.

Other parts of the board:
U$1: OSHW-LOGO-L

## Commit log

2014-07-03 Add Solidworks and STL files for case
    [Assem2.SLDASM, case.SLDPRT, case.SLDPRT.SLDASM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]
2014-07-07 Add Bill of Materials
2014-07-07 Update Bill Of Materials.md
2014-07-11 Add more steps to Fritzing files with Images
    [Fritzing Diagram Full.fzz, Fritzing Diagram GND-Wires.fzz, Fritzing Diagram LED-Wires.fzz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]
2014-07-11 Fix Transparency on Breadboard GND-Wires.png
2014-07-11 Clean up Breadboard Images
    • add 200px border around images
    • remove stray white pixels
2015-06-24 Update Bill Of Materials.md
    Complete overhaul for 2015
2015-06-25 Update PCB design for this year, minor tweaks
    [Sch1.brd]
2015-06-25 Regenerate GERBER files
    [DRILEGEND.CFG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]
2015-06-25 Adjust markings for Ribbon Cable connector
2015-06-25 Add downgrade cable to BOM
    Added Downgrade Cable to the BOM to work with the 40 pin Pi 2 GPIO header
2015-06-25 Add our estimated value from Bay Area Circuits
2015-06-25 Add disclaimer on soldering materials
2015-06-25 add break in connector outline for via
    [Sch1.brd]
2015-06-26 move position of Downgrade cable in PCB list
    • Moved the position of the Downgrade cable in the PCB materials list to better match the previous list
2015-06-26 italicize materials that can be reused
2015-06-26 Correct subheading for PCBs section
    • change subsection of the PCBs section to match that of others in the document
2015-06-26 Round corners of PCB
    • Round corners of PCB
    • move mounting holes to all four corners
    [Sch1.brd]
2015-06-26 Change mounting hole drill sizes
    • change mounting holes from 2.8mm to 3mm
    • updated version number
    [Sch1.brd]
2015-06-26 Change width of back silkscreen fill
    [Sch1.brd]
2015-06-26 update Gerber Files
2015-06-26 Add front outline and socket fix
    + Add outline to frong
    • fix box header outline
    [Sch1.brd]
2015-06-26 update version
    [Sch1.brd]
2015-06-26 Export new Gerber files
    [Sch1.GBL, Sch1.GBO, Sch1.GBS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]
2015-06-27 Update and reorganize solid works files
    [Assem2.SLDASM, Bottom.SLDDRW, Bottom.SLDPRT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]
2015-06-27 more tweaks to Solidworks files
    [Case Assembled.SLDDRW, PCB.SLDPRT, case.SLDDRW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]
2015-06-27 add Screw and Spacer files
    (assembly should now work)
    [Screw.SLDPRT, spacer.SLDPRT]
2015-06-27 remove free version disclaimer from assembly drawing
2015-06-27 add breadboard paths frizzing file
    [Breadboard paths.fzz]
2015-06-28 add PCB illustrations for front and back
2015-06-29 Add hardware to Bill of Materials
2015-06-30 Reorganize part files
    [Bottom.SLDPRT, Button Assembly.SLDASM, Cap.SLDPRT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]
2015-06-30 More updates
    [Assembled PCB.SLDASM, Button Assembly.SLDASM, Cap.SLDPRT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]
2015-06-30 Add final assembly
    [Assembled PCB.SLDASM, Assembled.SLDASM, Case Assembled.SLDASM]
2015-06-30 ¯\_(ツ)_/¯
2015-07-01 more updating
    [Assembled PCB.SLDASM, Assembled.SLDASM]
2015-07-07 update case
    [case.SLDPRT, case.STL]
2015-07-07 lower tolerance around buttons slightly
    [case.SLDPRT]
2015-07-07 raise height of LEDs in case for flexibility
    [Assembled PCB.SLDASM]
2015-07-07 update case file to match recent changes
    [case.SLDPRT, case.STL]
2015-07-07 reorient case and assembly models for better viewing
    [Assembled.SLDASM, case.SLDPRT]
2015-07-07 final changes to assembly
    [Assembled.SLDASM]
2015-07-07 remove temporary files
    i thought i chose to ignore these…
2015-07-07 add version number to part model
    [case.SLDPRT, case.STL]
2015-07-07 Revert 1682bb6..73902a2
    This rolls back to commit 1682bb6f1faba2033edf4862bf592824650a5027.
    [case.SLDPRT, case.STL]
2015-07-07 add version number to case file
    [case.STL]
2015-07-07 Revert "add version number to case file"
    This reverts commit f0a68ef5de1f65eca20f909cd8c7334c396250a6.
    [case.STL]
2015-07-10 Configure different sizes and colors of LEDs
    [LED Head.SLDPRT, LED Leads.SLDPRT, LED short.SLDASM]
2015-07-10 add DFX file
    [Bottom.DWG]
2016-06-13 Update BOM for raspberry pis for 2016
2016-06-13 Consolidate BOM since we are no longer running APPcamp
2016-07-12 fix bill of materials
2016-07-14 update case file
    [case.STL]

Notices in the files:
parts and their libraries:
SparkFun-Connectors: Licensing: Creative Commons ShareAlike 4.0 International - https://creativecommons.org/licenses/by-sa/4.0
